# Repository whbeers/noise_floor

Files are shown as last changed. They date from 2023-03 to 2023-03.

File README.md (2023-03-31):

# Noise Floor interface board collection

This is set of interface boards to speed effect pedal development, continuing my efforts to learn PCB design with [KiCAD](https://www.kicad.org/).

### IO and Switch boards
The first board is an audio input and power board, featuring:
  - Switched DC barrel jack supporting either a 9VDC center negative supply or 9V battery
  - Mono audio jacks w/ switched input circuit (ring/ground shorted to sleeve on insertion)
  - Basic power input protection

The IO PCB is designed to fit in a standard 125B enclosure.

The second board simplifies effect bypass via a 3PDT switch adapter with an LED indicator.

#### Connectivity (cabled)
IO, Effect, and Switch boards are connected using four-circuit [Molex PicoBlade](https://www.molex.com/molex/products/family/picoblade?parentKey=wire_to_board_connectors) connectors.

Headers are labelled symmetrically from the perspective of the IO board:
 - **S**1 on IO Board <-> **S**1 on **S**witch Board
 - **S**2 on IO Board <-> **S**2 on **S**witch Board
 - **E**1 on IO Board <-> **E**1 on **E**ffect Board

### UX PCB (experimental)
The third and newest (experimental) board is a UX board providing a standard superset of potentiometers and switches. It is intended to connect to an effects board using two 25-position [Amphenol "Conan Lite"](https://www.amphenol-cs.com/product-series/conan-lite-1-00mm.html) board-to-board connectors.

The current iteration of the UX board supports six potentiometers and three SPDT switches, but alternative control layouts are an obvious extension. Each potentiometer on the current prototype can be adjusted using optional parallel resistors (SMD 1206) to tweak the taper and total resistance.

#### Connectivity (board-to-board)
The effect and UX boards are connected using [Amphenol "Conan Lite"](https://www.amphenol-cs.com/product-series/conan-lite-1-00mm.html) board-to-board connectors. Only a single UX board variety currently exists, supporting a superset of six potentiometers and three SPDT switches. As the UX board is in the experimental/proof-of-concept phase, the pin assignment should be considered preliminary and subject to change.

Current connector allocation:
 - 6x Potentiometers x 3 (CCW, Wiper, CW) = 18
 - 3x SPDT switches x 3 (NO, COM, NC) = 9
 - 4x Reserved for ground
 - Total used: 31
 - Remaining for expansion: 19
 
Ideas for future boards / changes:
 - Allocate connector positions for a single DPDT switch (+3, reusing 3 from an existing SPDT)
 - Incorporate linear potentiometers into an alternate IO board
 - Allocate at least 12 positions for "flexible use" (enough to support a 4PDT switch)
 - Allocate positions to drive (RGB?) LEDs with standardized current-limiting resistors

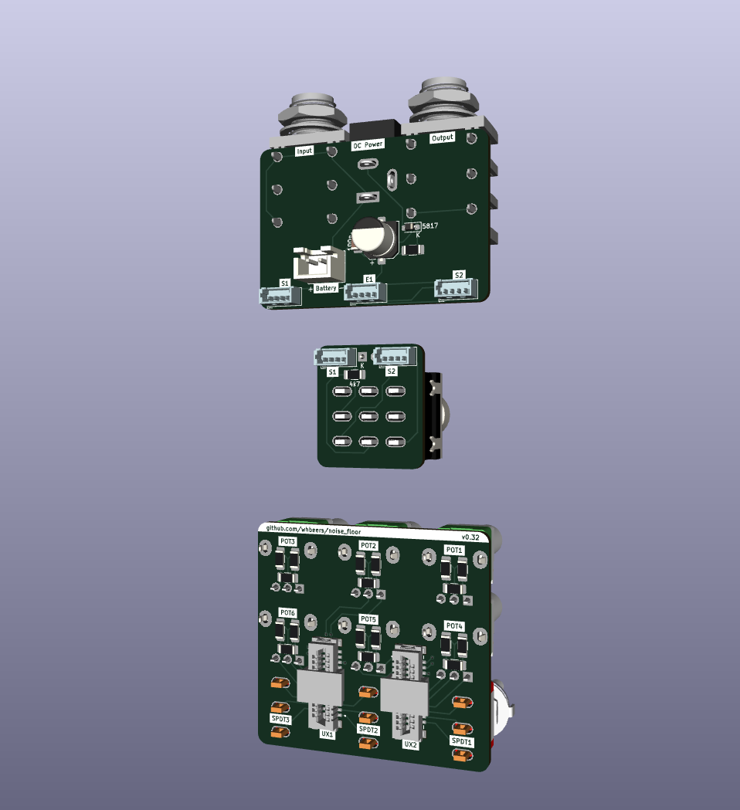
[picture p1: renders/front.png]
Front render

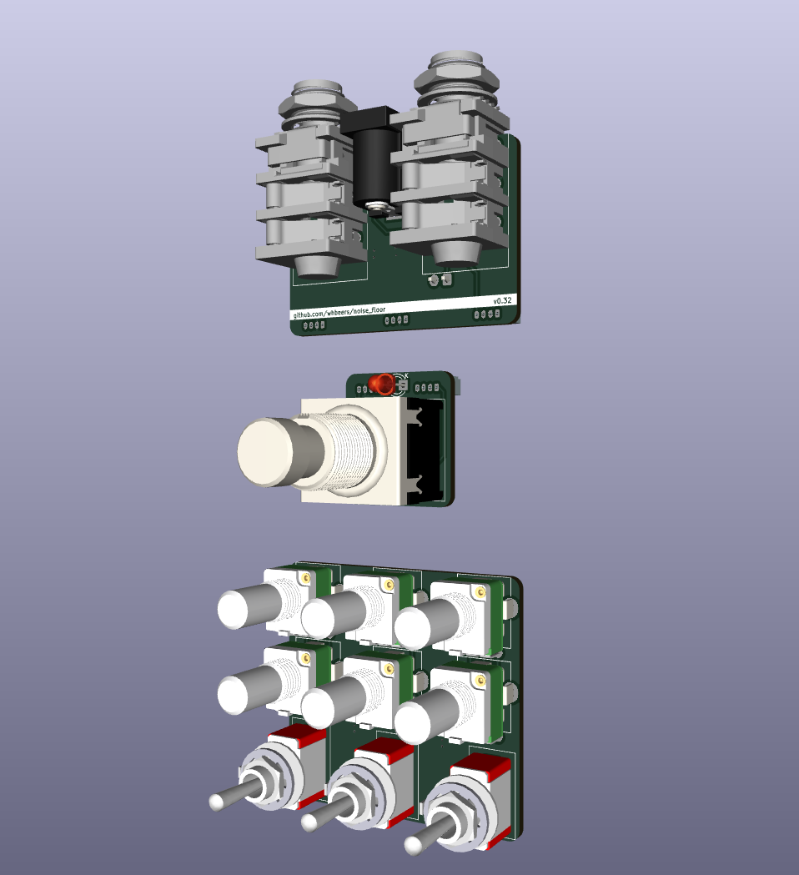
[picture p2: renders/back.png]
Back render

Schematic SVG
[Schematic PDF](schematics/noise_floor-latest.pdf)

## Credit

The original idea and specific bypass circuit is inspired by many manufacturers of utility PCBs and well-known circuits for 3PDT-based effect bypass, notably [PedalPCB's 3PDT breakout](https://www.pedalpcb.com/product/3pdt/), augmented to suit my needs.

Thanks as always to the folks on the [freestompboxes.org](https://www.freestompboxes.org/) forum for feedback and suggestions.

Potentiometer, 3PDT footswitch, and DC barrel jack 3D models courtesy [Vasily Kashirin](https://grabcad.com/vasily.kashirin-1).

SPDT toggle switch 3D model courtesy [Stephanie Schwecke](https://grabcad.com/stephanie.schwecke-1).

Conan Lite footprints adapted from the 51-position footprints available from SnapEDA: [Header](https://www.snapeda.com/parts/10162582-1134151LF/Amphenol%20ICC%20(FCI)/view-part/), [Receptacle](https://www.snapeda.com/parts/10162581-3134151LF/Amphenol%20ICC%20(FCI)/view-part/).([Additional license details](hardware/SnapEDA_Licensing.txt)). 3D models courtesy Amphenol.

*I am not affiliated with any of the brands, sites, or products named in this overview.*

## Future plans

 - Build an IO board that includes a TRS expression pedal input (started this way, but found it hard to fit in a 125B enclosure)
 - Support stereo operation via relays, optoisolators, or a "millenium" switch

## Versioning

My pcb designs utilize the following versioning scheme (I'll add to this as I produce more revisions):
 - v0.0XX: A candidate design that has not yet been produced and tested.
 - v0.XX: A design that has been produced, tested, and any initial errors addressed.

## Name
*The name Noise Floor is a reflection of the function of the board (a substrate for pedals and bypass circuit) and security nerdery.*

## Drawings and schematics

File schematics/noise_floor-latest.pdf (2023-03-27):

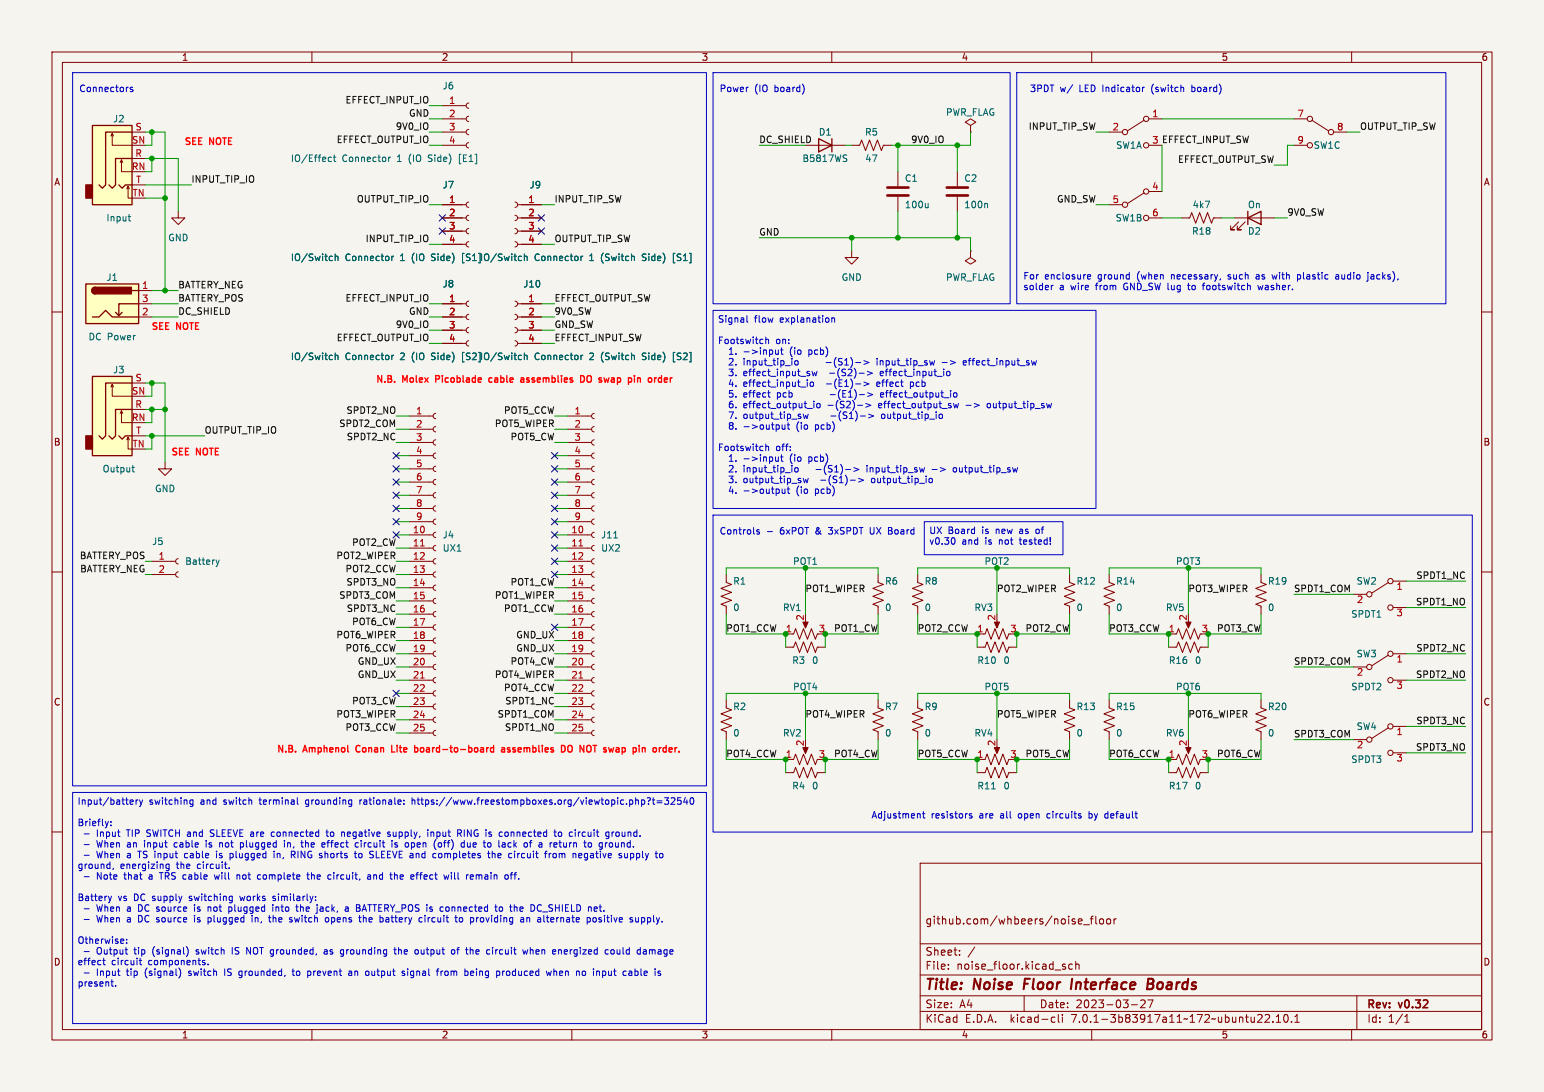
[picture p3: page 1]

Id: 1/1 Title: Noise Floor Interface Boards

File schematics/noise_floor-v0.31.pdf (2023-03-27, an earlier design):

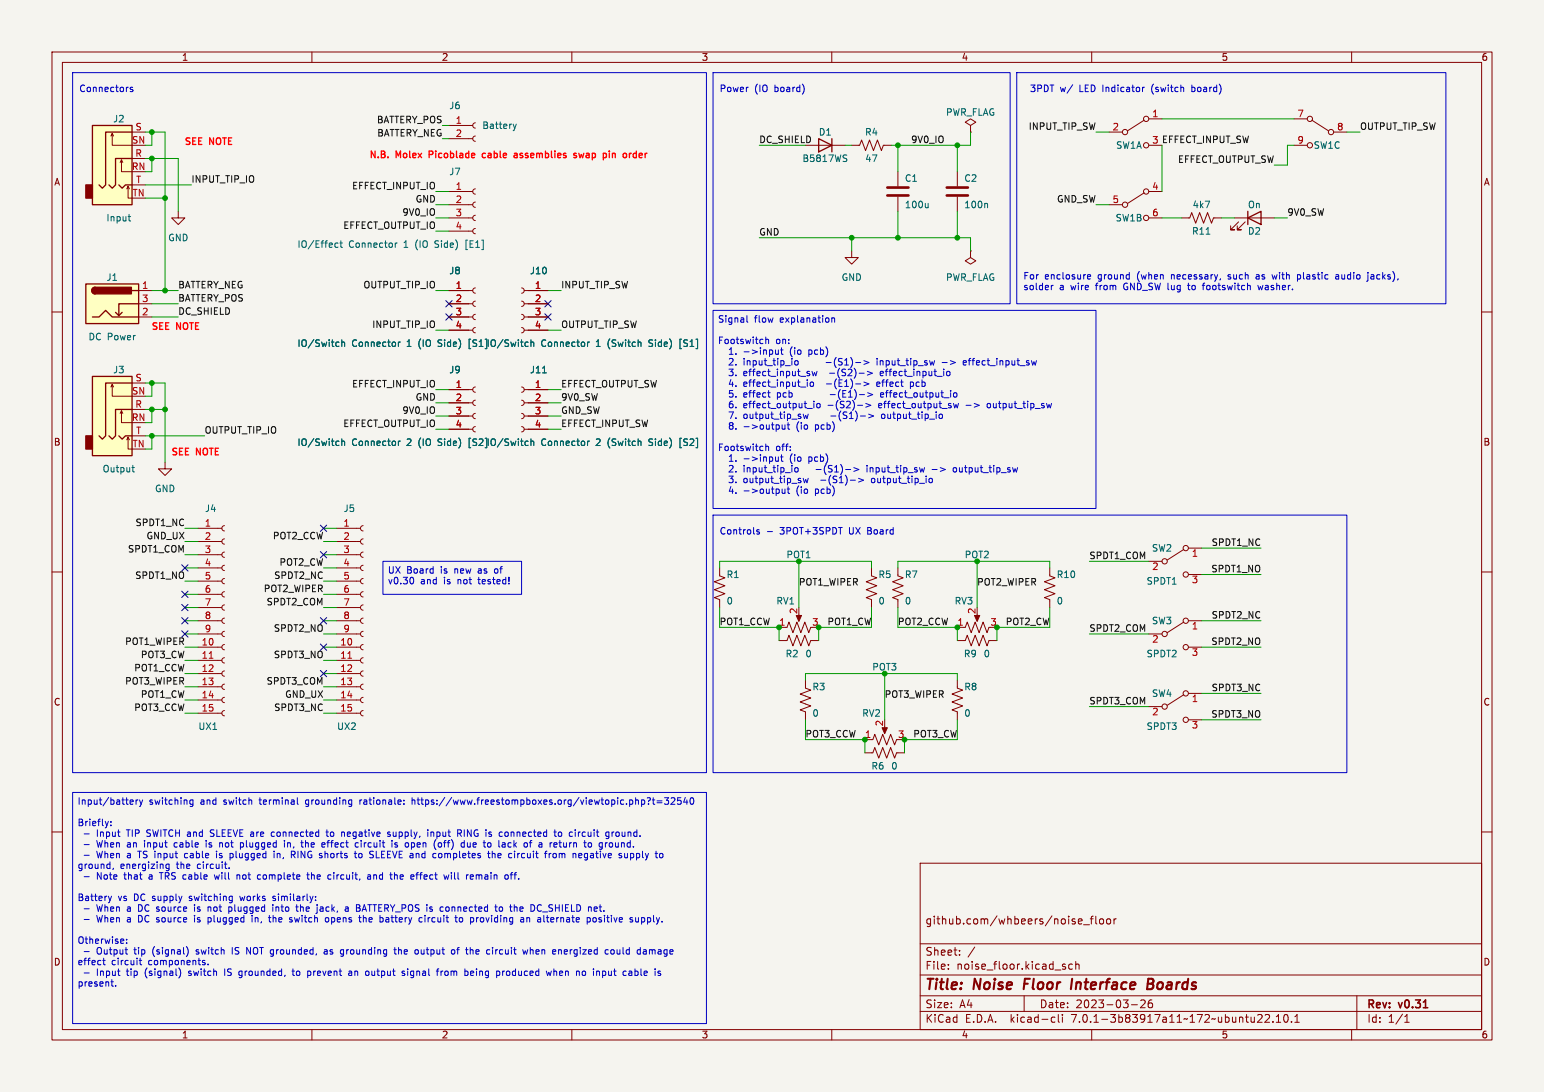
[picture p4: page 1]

File: noise_floor.kicad_sch Sheet: / github.com/whbeers/noise_floor

Id: 1/1 Title: Noise Floor Interface Boards

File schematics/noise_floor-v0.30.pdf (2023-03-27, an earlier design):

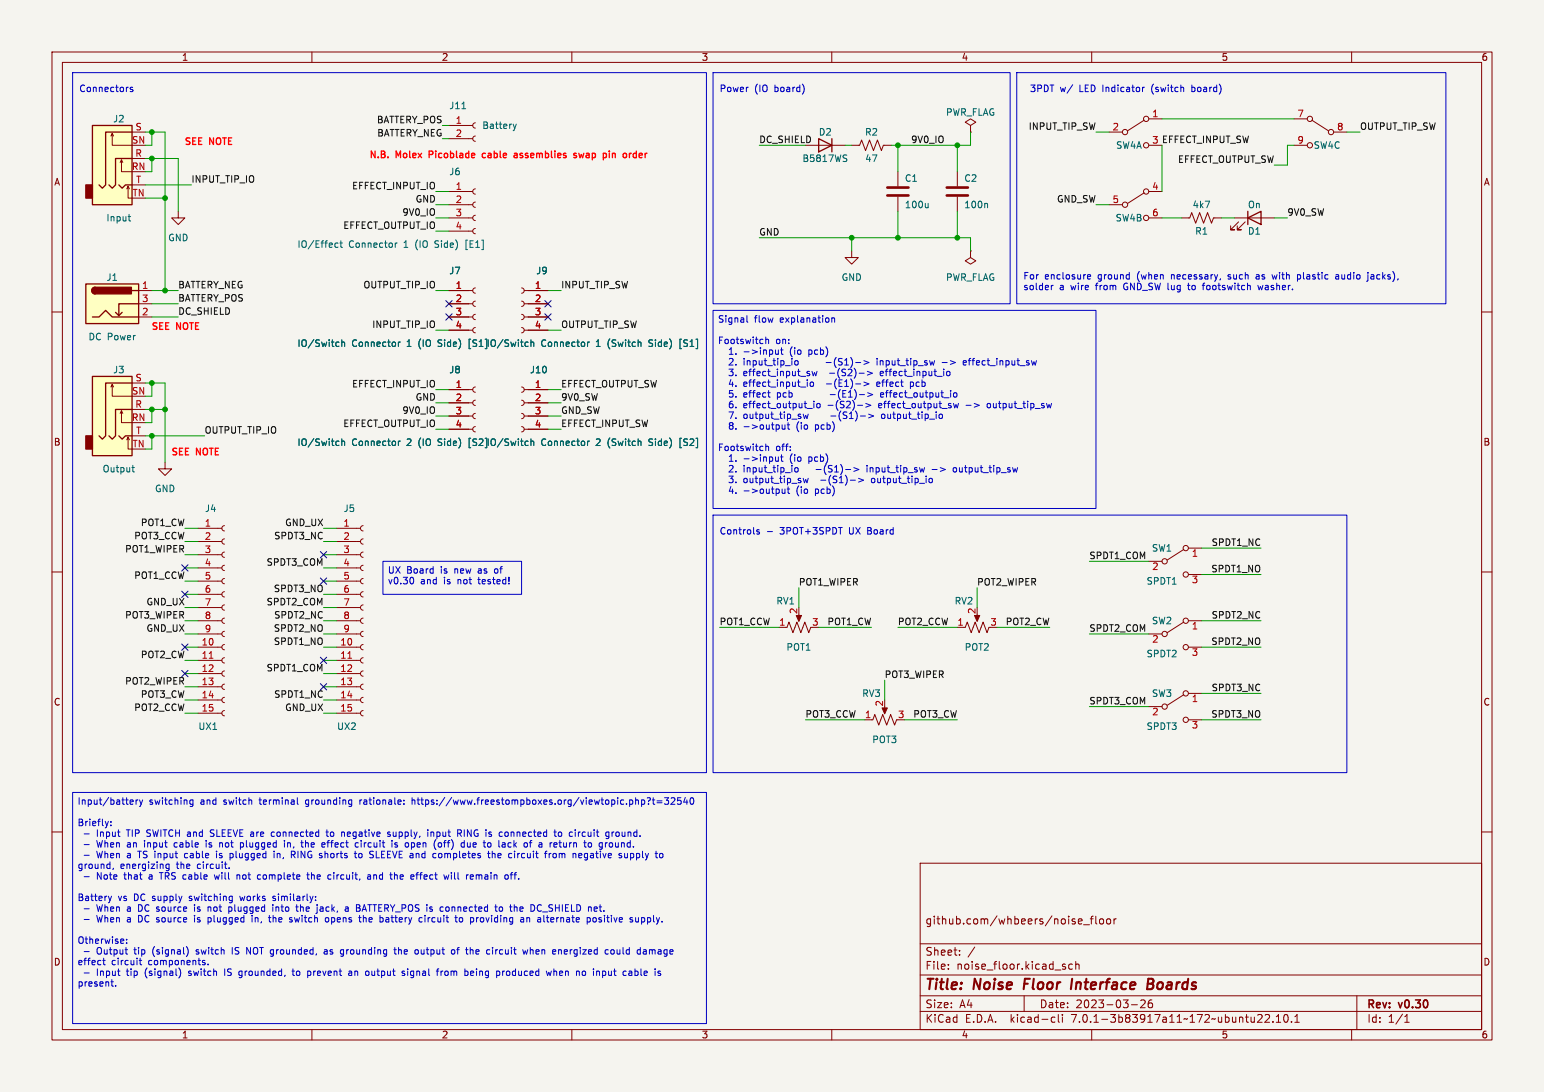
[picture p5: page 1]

File: noise_floor.kicad_sch Sheet: / github.com/whbeers/noise_floor

Id: 1/1 Title: Noise Floor Interface Boards

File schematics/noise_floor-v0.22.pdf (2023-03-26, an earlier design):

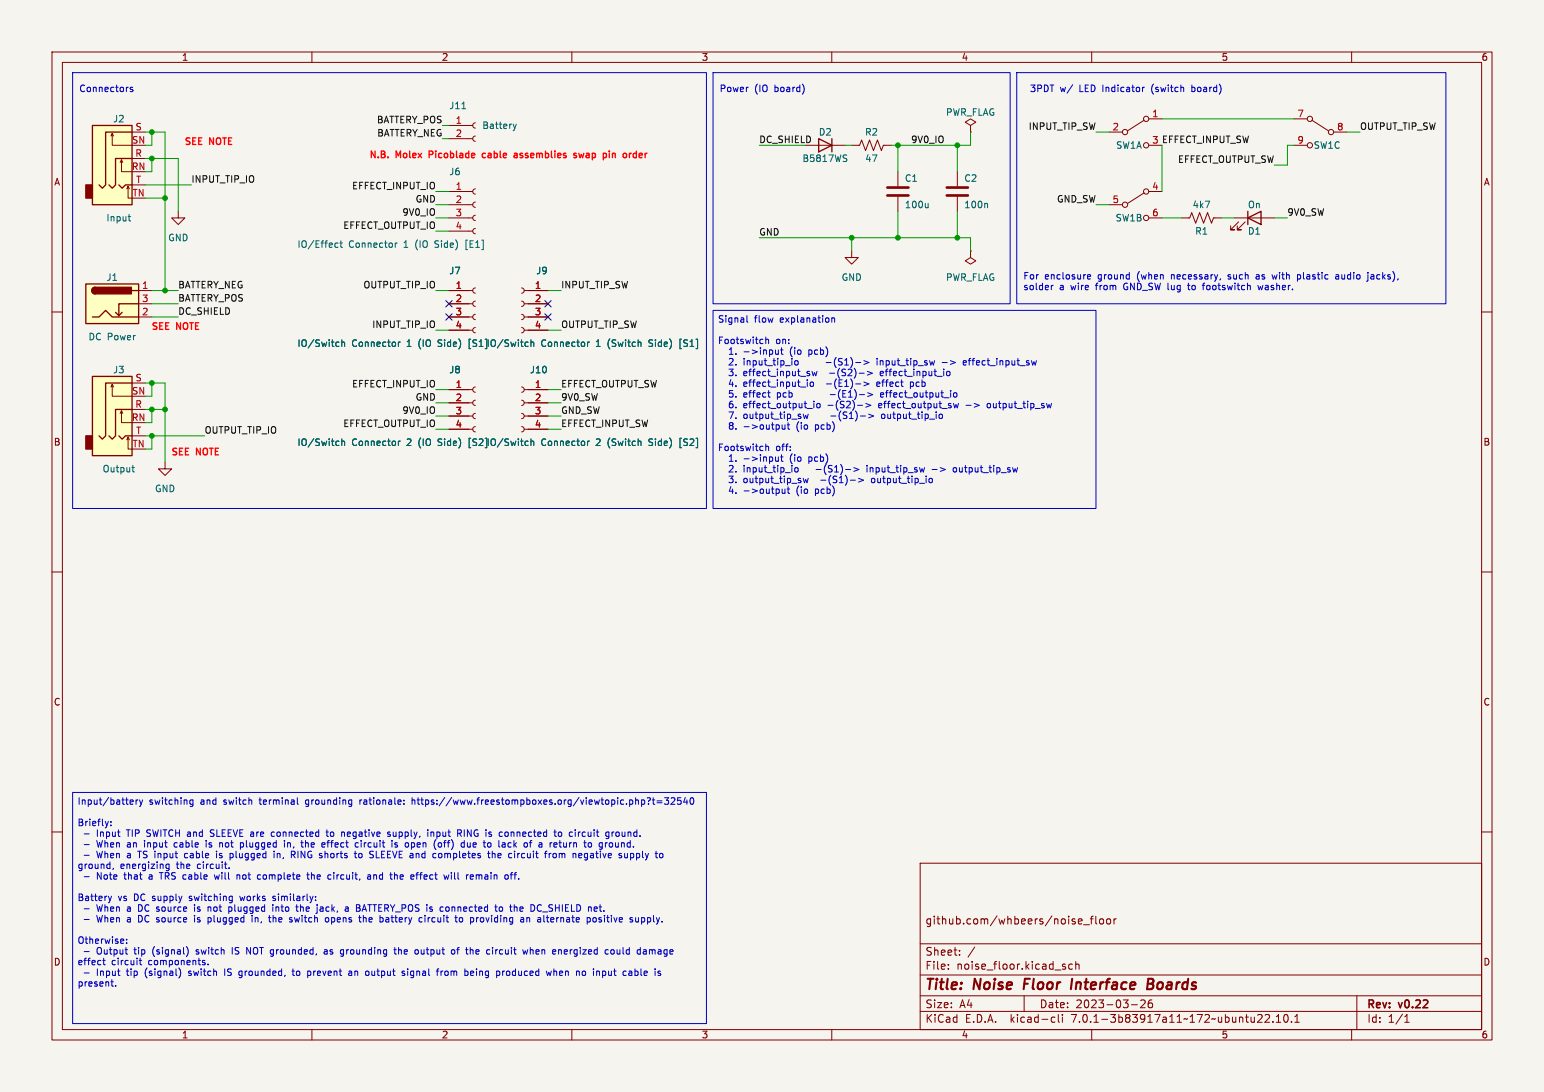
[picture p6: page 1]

File: noise_floor.kicad_sch Sheet: / github.com/whbeers/noise_floor

Id: 1/1 Title: Noise Floor Interface Boards

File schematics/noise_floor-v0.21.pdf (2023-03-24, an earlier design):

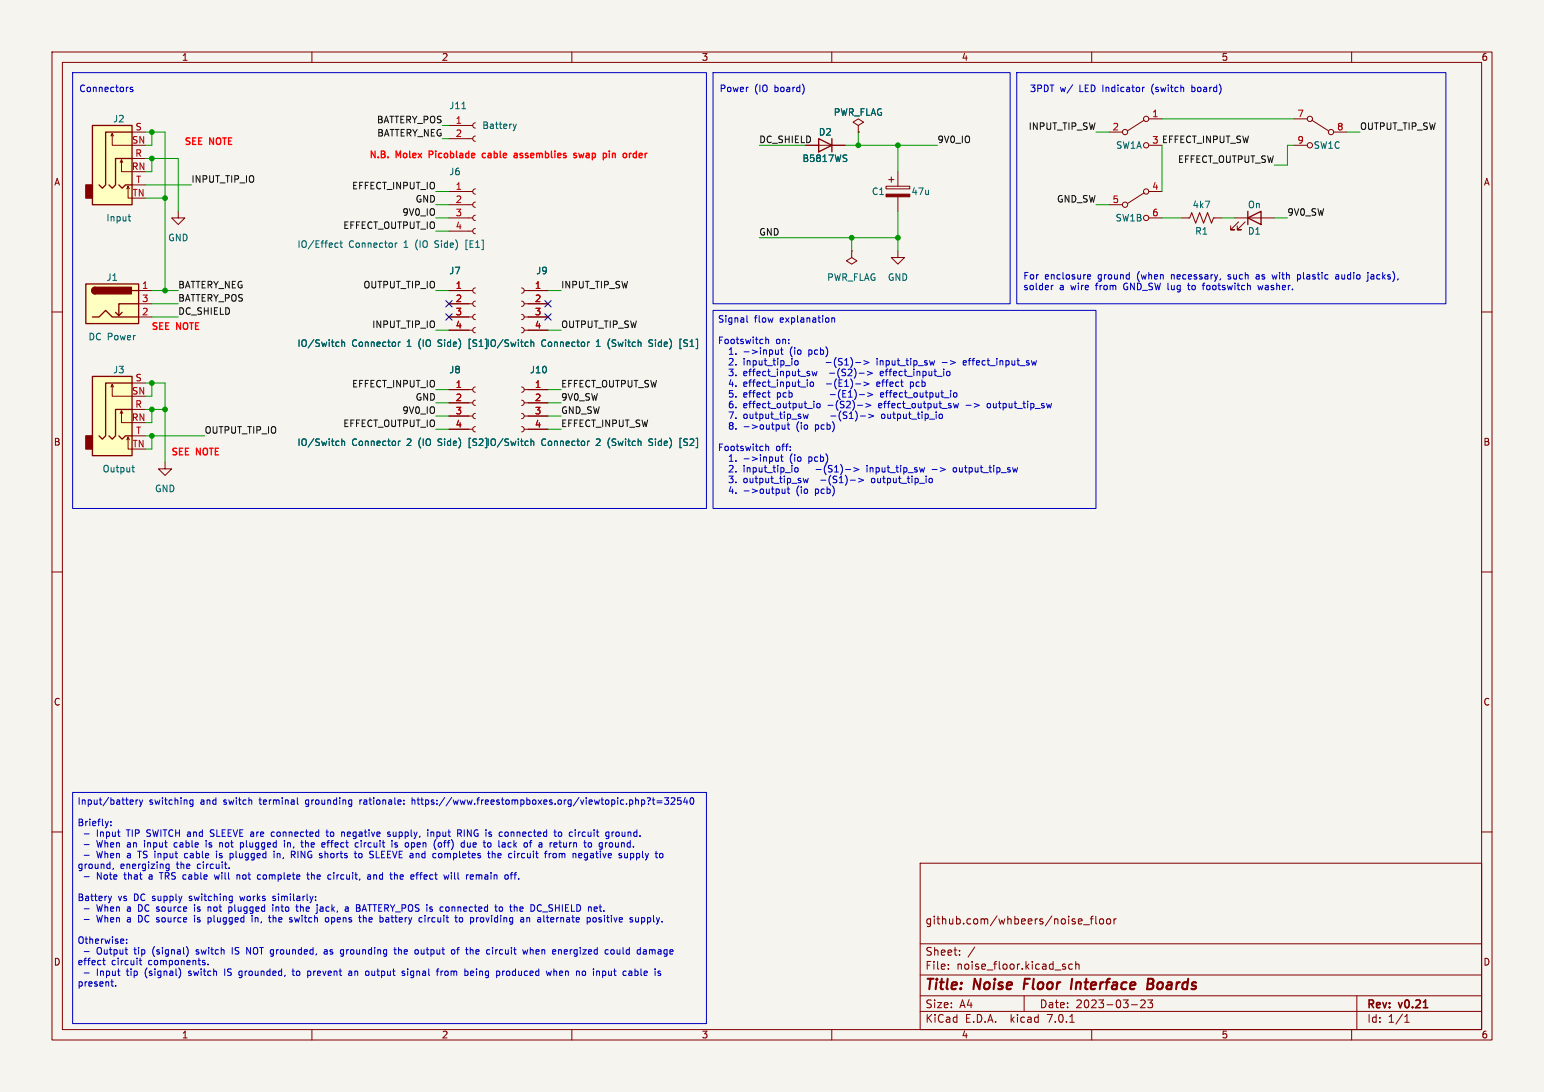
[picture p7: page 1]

File: noise_floor.kicad_sch Sheet: / github.com/whbeers/noise_floor

Id: 1/1 Title: Noise Floor Interface Boards

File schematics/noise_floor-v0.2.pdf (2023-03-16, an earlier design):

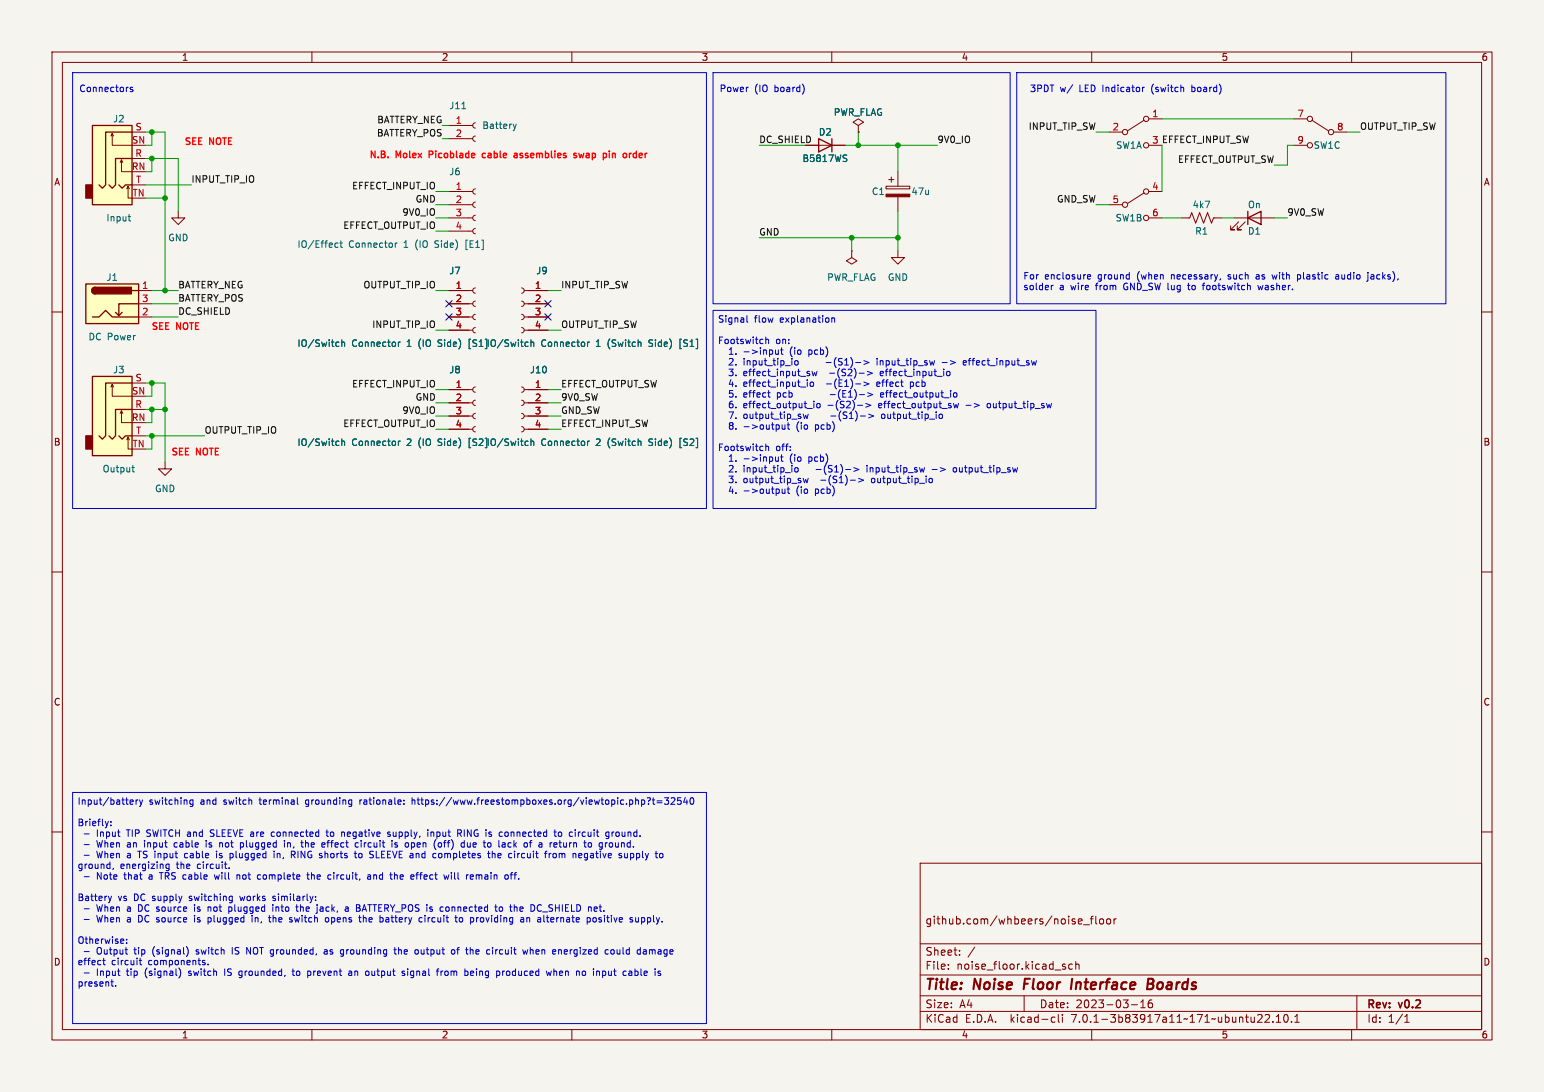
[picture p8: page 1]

Power (IO board) N.B. Molex Picoblade cable assemblies swap pin order SEE NOTE

File: noise_floor.kicad_sch Sheet: / github.com/whbeers/noise_floor

Id: 1/1 Title: Noise Floor Interface Boards

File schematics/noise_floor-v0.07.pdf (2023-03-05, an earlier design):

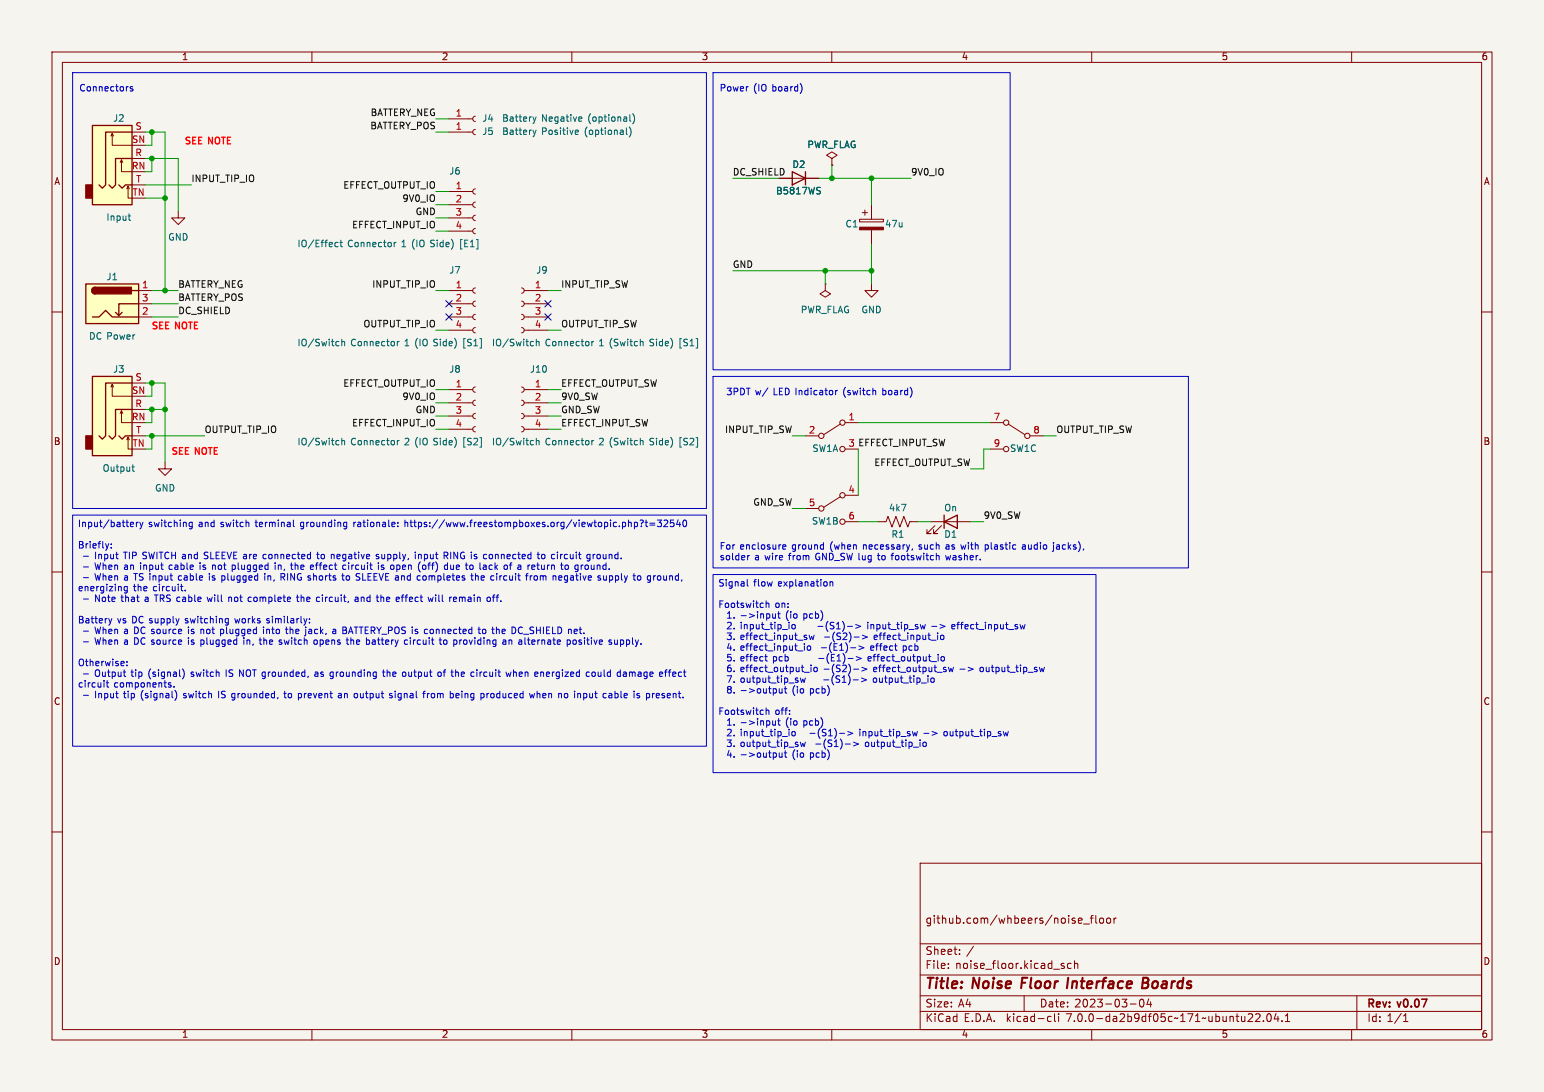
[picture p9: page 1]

File: noise_floor.kicad_sch Sheet: / github.com/whbeers/noise_floor

Id: 1/1 Title: Noise Floor Interface Boards

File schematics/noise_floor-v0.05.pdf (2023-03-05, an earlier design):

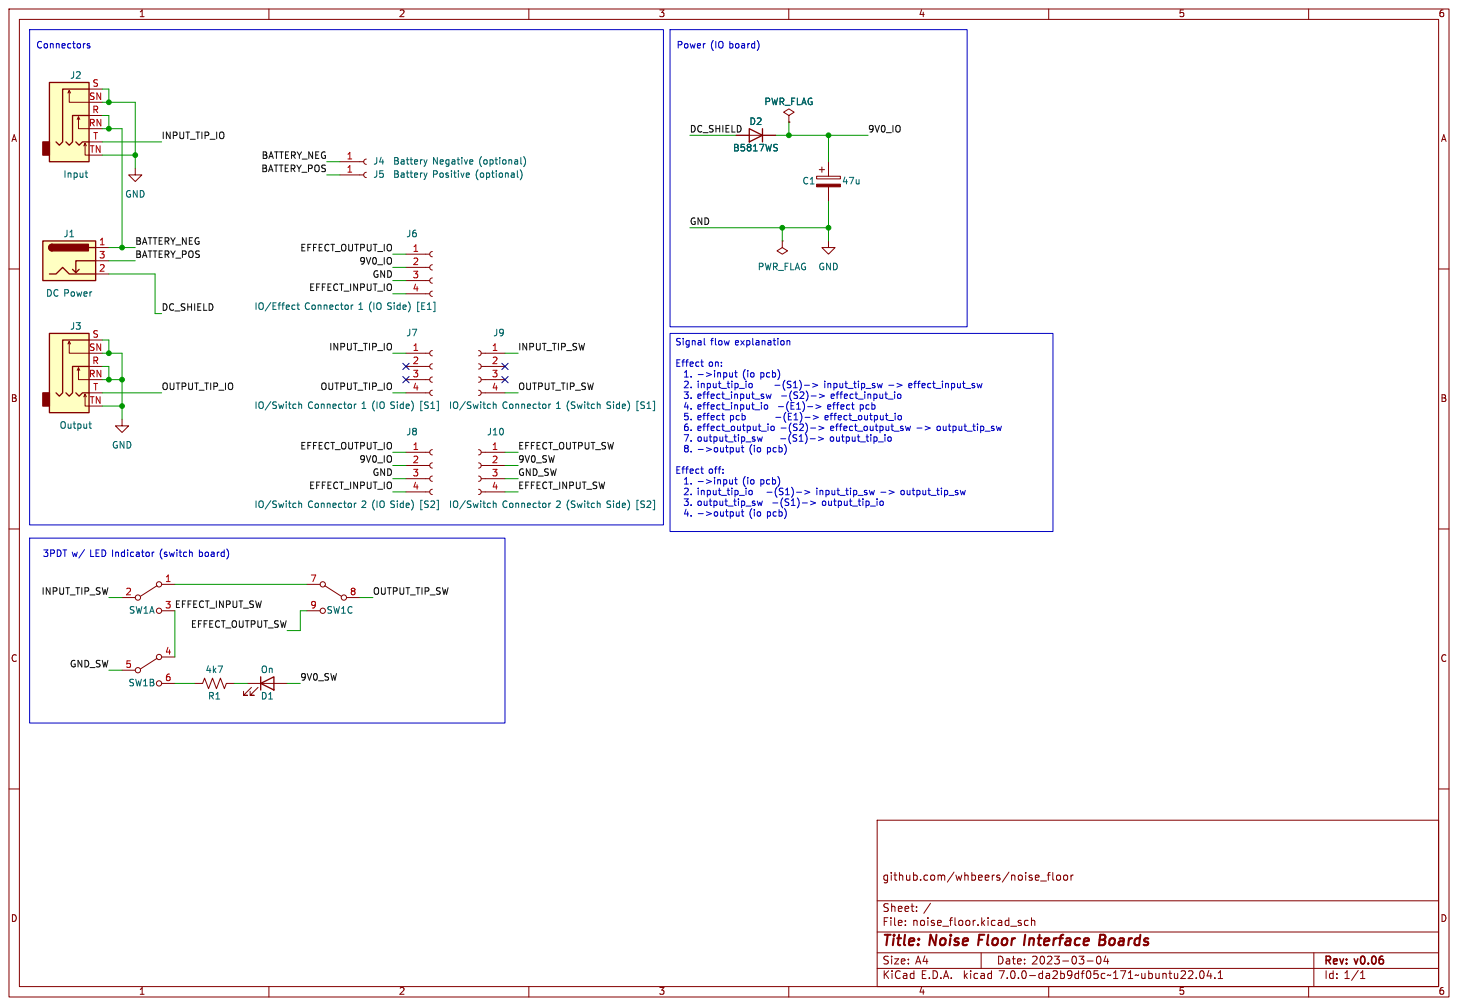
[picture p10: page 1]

File: noise_floor.kicad_sch Sheet: / github.com/whbeers/noise_floor D1 On

Id: 1/1 Title: Noise Floor Interface Boards

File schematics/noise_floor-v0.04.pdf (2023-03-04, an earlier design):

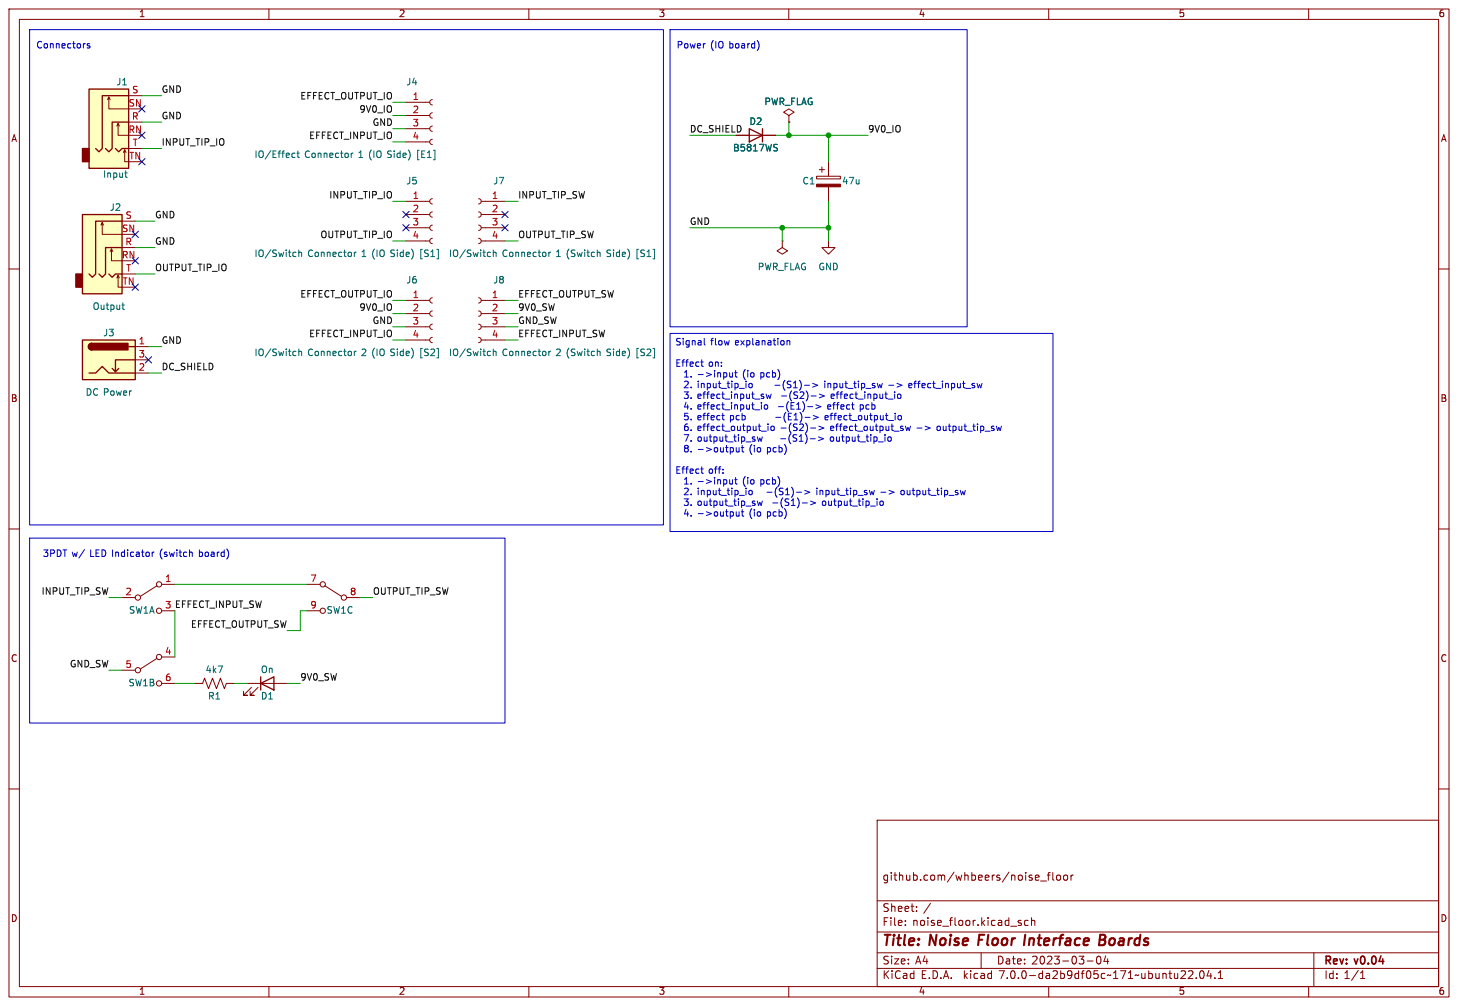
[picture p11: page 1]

File: noise_floor.kicad_sch Sheet: / github.com/whbeers/noise_floor

Id: 1/1 Title: Noise Floor Interface Boards

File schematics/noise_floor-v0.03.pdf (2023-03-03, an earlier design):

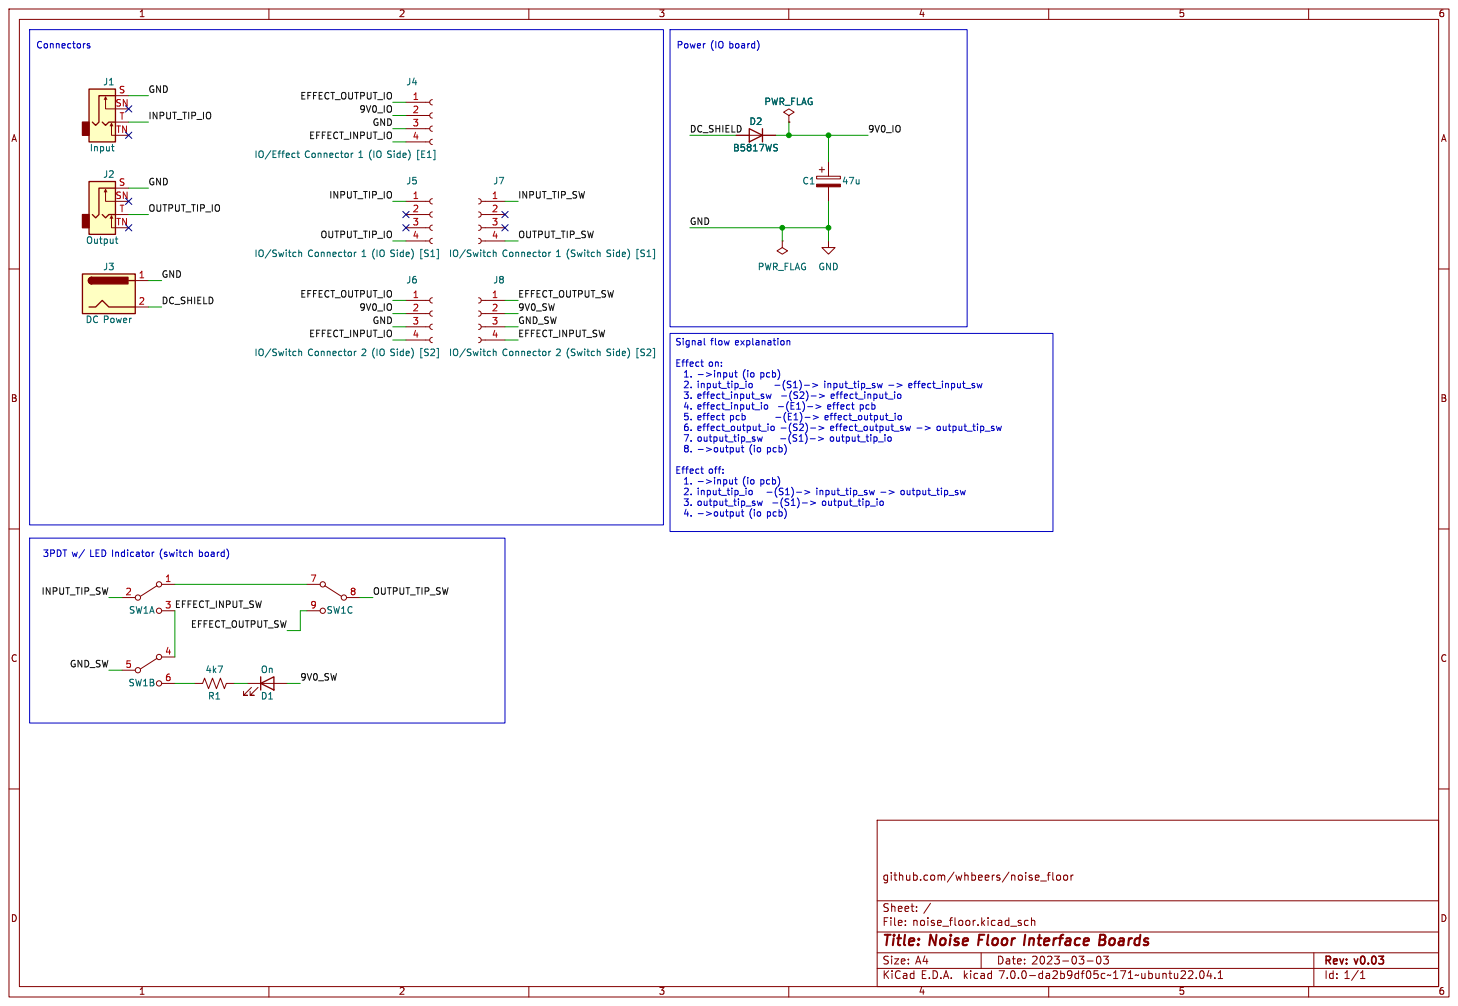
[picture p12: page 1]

File: noise_floor.kicad_sch Sheet: / github.com/whbeers/noise_floor

Id: 1/1 Title: Noise Floor Interface Boards

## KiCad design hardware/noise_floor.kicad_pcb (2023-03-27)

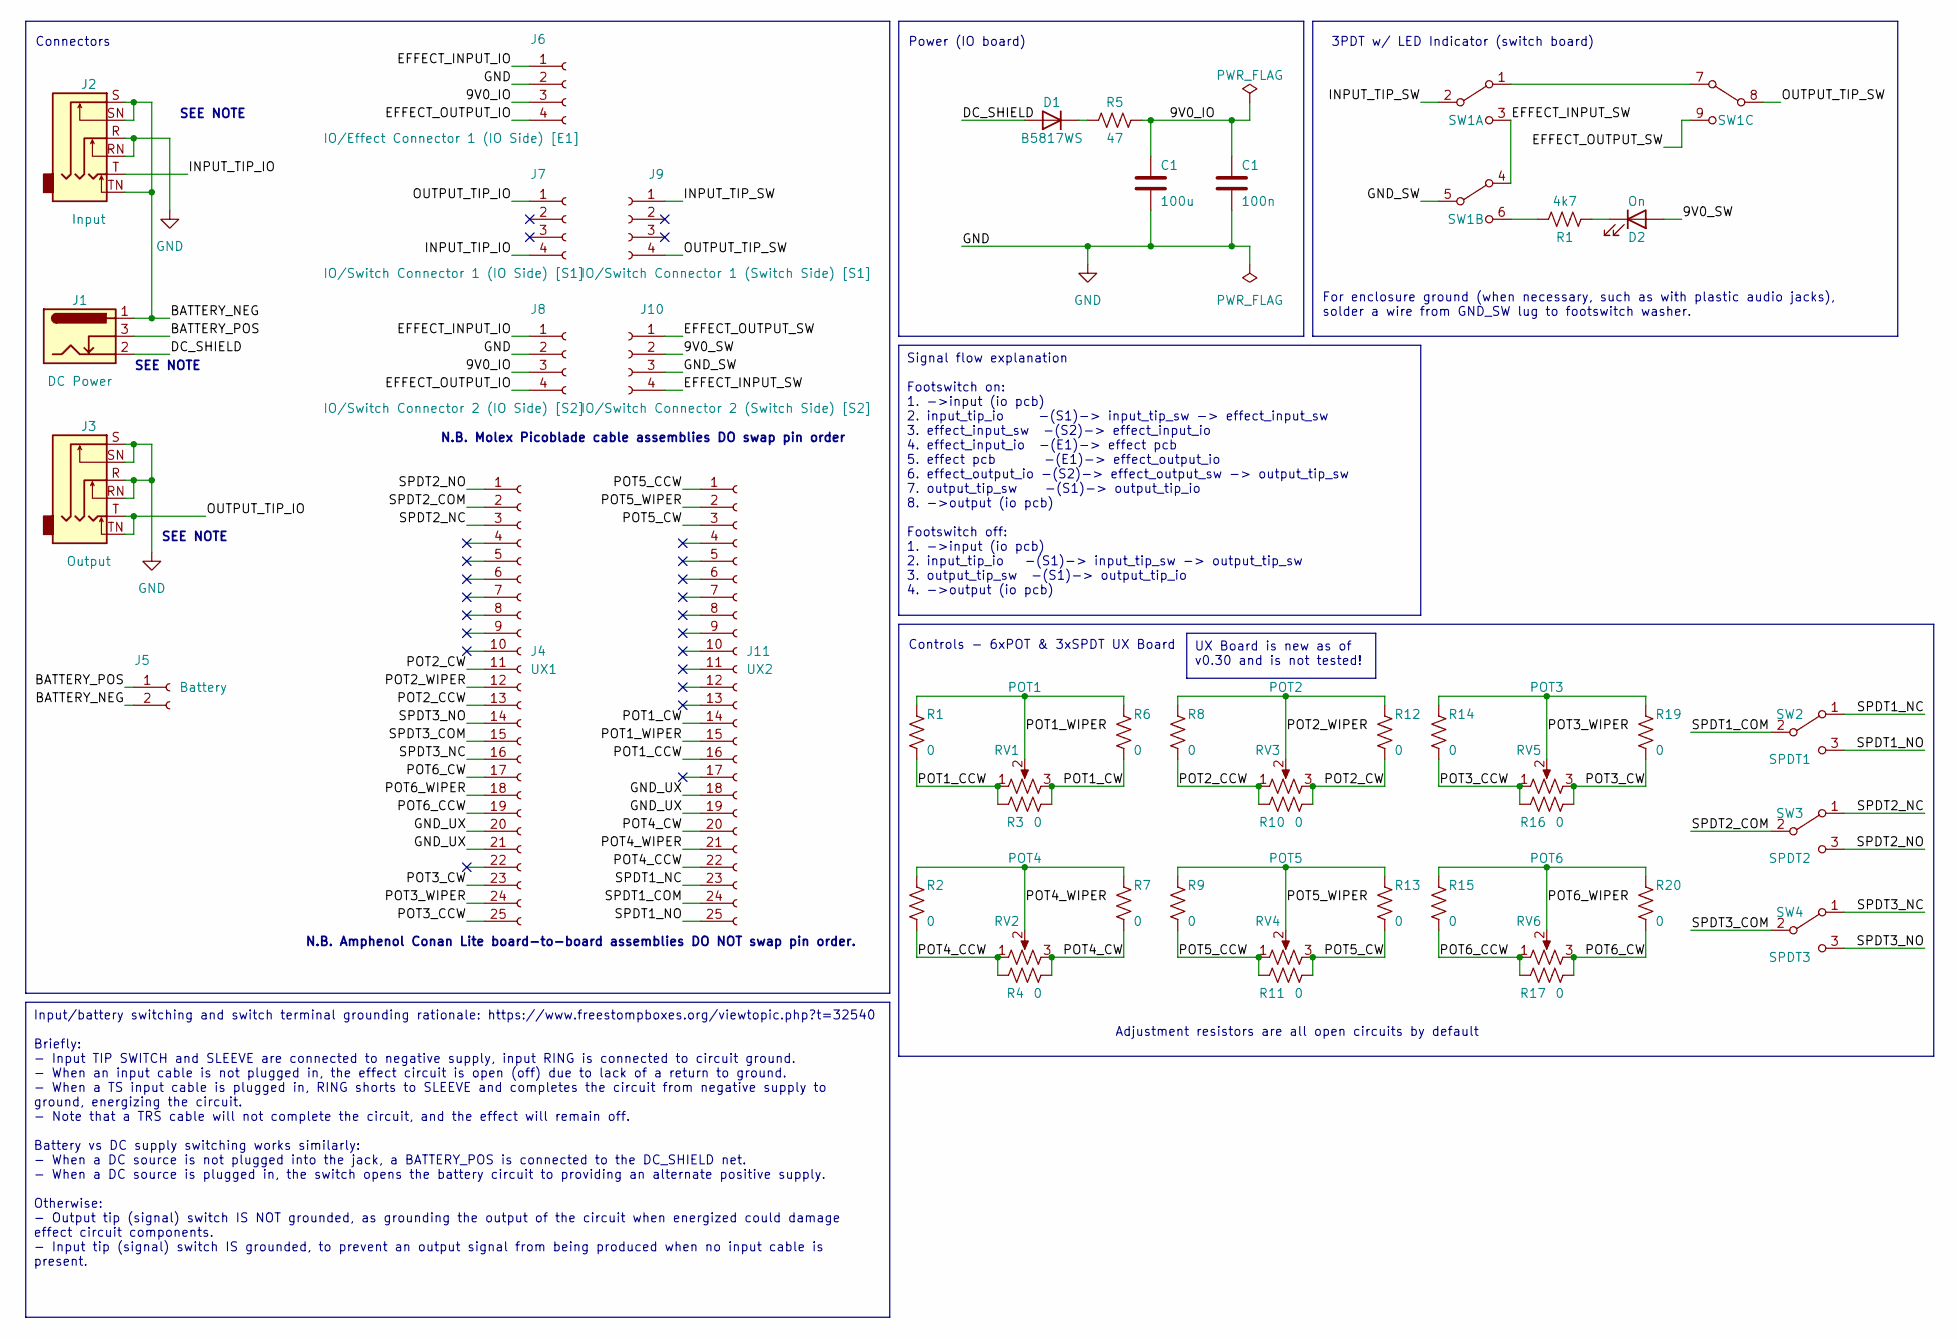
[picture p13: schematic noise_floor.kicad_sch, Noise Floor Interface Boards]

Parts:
C1: 100n; C_1206_3216Metric
D1: B5817WS; D_SOD-323_HandSoldering
D2: On; LED_D3.0mm
J1: DC Power; BarrelJack_GCT_DCJ200-10-A_Horizontal_with_3DModel_from_Vas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
J2: Input; ACJS-MHOM
J3: Output; ACJS-MHOM
J4: UX1; Amphenol_Receptacle_25pin_10162581-3134125LF
J5: Battery; JST_XH_B2B-XH-A_1x02_P2.50mm_Vertical
J6: IO/Effect Connector 1 (IO Side) [E1]; Molex_PicoBlade_53047-0410_1x04_P1.25mm_Vertical_with_3D_Mo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
J7: IO/Switch Connector 1 (IO Side) [S1]; Molex_PicoBlade_53047-0410_1x04_P1.25mm_Vertical_with_3D_Mo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
J8: IO/Switch Connector 2 (IO Side) [S2]; Molex_PicoBlade_53047-0410_1x04_P1.25mm_Vertical_with_3D_Mo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
J9: IO/Switch Connector 1 (Switch Side) [S1]; Molex_PicoBlade_53047-0410_1x04_P1.25mm_Vertical_with_3D_Mo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
J10: IO/Switch Connector 2 (Switch Side) [S2]; Molex_PicoBlade_53047-0410_1x04_P1.25mm_Vertical_with_3D_Mo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
J11: UX2; Amphenol_Receptacle_25pin_10162581-3134125LF
R1: 4k7; R_1206_3216Metric_Pad1.30x1.75mm_HandSolder
R2, R3, R4, R6, R7, R8, R9, R10, R11, R12, R13, R14, R15, R16, R17, R19, R20: 0; R_1206_3216Metric_Pad1.30x1.75mm_HandSolder
R5: 47; R_1206_3216Metric_Pad1.30x1.75mm_HandSolder
RV1: POT1; Potentiometer_Alpha_RD901F-40-00D_Single_Vertical_with_3DMo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
RV2: POT4; Potentiometer_Alpha_RD901F-40-00D_Single_Vertical_with_3DMo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
RV3: POT2; Potentiometer_Alpha_RD901F-40-00D_Single_Vertical_with_3DMo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
RV4: POT5; Potentiometer_Alpha_RD901F-40-00D_Single_Vertical_with_3DMo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
RV5: POT3; Potentiometer_Alpha_RD901F-40-00D_Single_Vertical_with_3DMo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
RV6: POT6; Potentiometer_Alpha_RD901F-40-00D_Single_Vertical_with_3DMo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
SW1: Footswitch; SW_3PDT_SOLDER_LUGS
SW2: SPDT1; SW_SPDT_SOLDER_LUGS
SW3: SPDT2; SW_SPDT_SOLDER_LUGS
SW4: SPDT3; SW_SPDT_SOLDER_LUGS

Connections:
/9V0_IO: C1.1, J6.3, J8.3, R5.1; also elsewhere on the board
/9V0_SW: D2.2 (A), J10.2
/BATTERY_NEG: J1.1, J2.S, J2.SN, J2.TN, J5.2
/BATTERY_POS: J1.3, J5.1
/DC_SHIELD: D1.2 (A), J1.2
/EFFECT_INPUT_IO: J6.1, J8.1
/EFFECT_INPUT_SW: J10.4, SW1.3 (A3), SW1.4 (B1)
/EFFECT_OUTPUT_IO: J6.4, J8.4
/EFFECT_OUTPUT_SW: J10.1, SW1.9 (C3)
/GND_SW: J10.3, SW1.5 (B2)
/GND_UX: J4.20, J4.21, J11.18, J11.19
/INPUT_TIP_IO: J2.T, J7.4
/INPUT_TIP_SW: J9.1, SW1.2 (A2)
/OUTPUT_TIP_IO: J3.T, J3.TN, J7.1
/OUTPUT_TIP_SW: J9.4, SW1.8 (C2)
/POT1_CW: J11.14, R3.1, R6.1, RV1.3
/POT2_CCW: J4.13, R8.1, R10.2, RV3.1
/POT2_CW: J4.11, R10.1, R12.1, RV3.3
/POT2_WIPER: J4.12, R8.2, R12.2, RV3.2
/POT3_CCW: J4.25, R14.1, R16.2, RV5.1
/POT3_CW: J4.23, R16.1, R19.1, RV5.3
/POT3_WIPER: J4.24, R14.2, R19.2, RV5.2
/POT4_CCW: J11.22, R2.1, R4.2, RV2.1
/POT4_CW: J11.20, R4.1, R7.1, RV2.3
/POT4_WIPER: J11.21, R2.2, R7.2, RV2.2
/POT5_CCW: J11.1, R9.1, R11.2, RV4.1
/POT5_CW: J11.3, R11.1, R13.1, RV4.3
/POT5_WIPER: J11.2, R9.2, R13.2, RV4.2
/POT6_CCW: J4.19, R15.1, R17.2, RV6.1
/POT6_CW: J4.17, R17.1, R20.1, RV6.3
/POT6_WIPER: J4.18, R15.2, R20.2, RV6.2
/SPDT1_COM: J11.24, SW2.2 (B)
/SPDT1_NC: J11.23, SW2.1 (A)
/SPDT1_NO: J11.25, SW2.3 (C)
/SPDT2_COM: J4.2, SW3.2 (B)
/SPDT2_NC: J4.3, SW3.1 (A)
/SPDT2_NO: J4.1, SW3.3 (C)
/SPDT3_COM: J4.15, SW4.2 (B)
/SPDT3_NC: J4.16, SW4.1 (A)
/SPDT3_NO: J4.14, SW4.3 (C)
GND: C1.2, J2.R, J2.RN, J3.R, J3.RN, J3.S, J3.SN, J6.2, J8.2; also elsewhere on the board
unnamed: D1.1 (K), R5.2
unnamed: SW1.1 (A1), SW1.7 (C1)

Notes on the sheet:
Input/battery switching and switch terminal grounding rationale: https://www.freestompboxes.org/viewtopic.php?t=32540 Briefly: - Input TIP SWITCH and SLEEVE are connected to negative supply, input RING is connected to circuit ground. - When an input cable is not plugged in, the effect circuit is op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
Signal flow explanation Footswitch on: 1. ->input (io pcb) 2. input_tip_io -(S1)-> input_tip_sw -> effect_input_sw 3. effect_input_sw -(S2)-> effect_input_io 4. effect_input_io -(E1)-> effect pcb 5. effect pcb -(E1)-> effect_output_io 6. effect_output_io -(S2)-> effect_output_sw -> output_tip_sw 7.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
UX Board is new as of v0.30 and is not tested!
Connectors
For enclosure ground (when necessary, such as with plastic audio jacks), solder a wire from GND_SW lug to footswitch washer.
3PDT w/ LED Indicator (switch board)
SEE NOTE
Power (IO board)
Controls - 6xPOT & 3xSPDT UX Board
N.B. Amphenol Conan Lite board-to-board assemblies DO NOT swap pin order.
Adjustment resistors are all open circuits by default
N.B. Molex Picoblade cable assemblies DO swap pin order

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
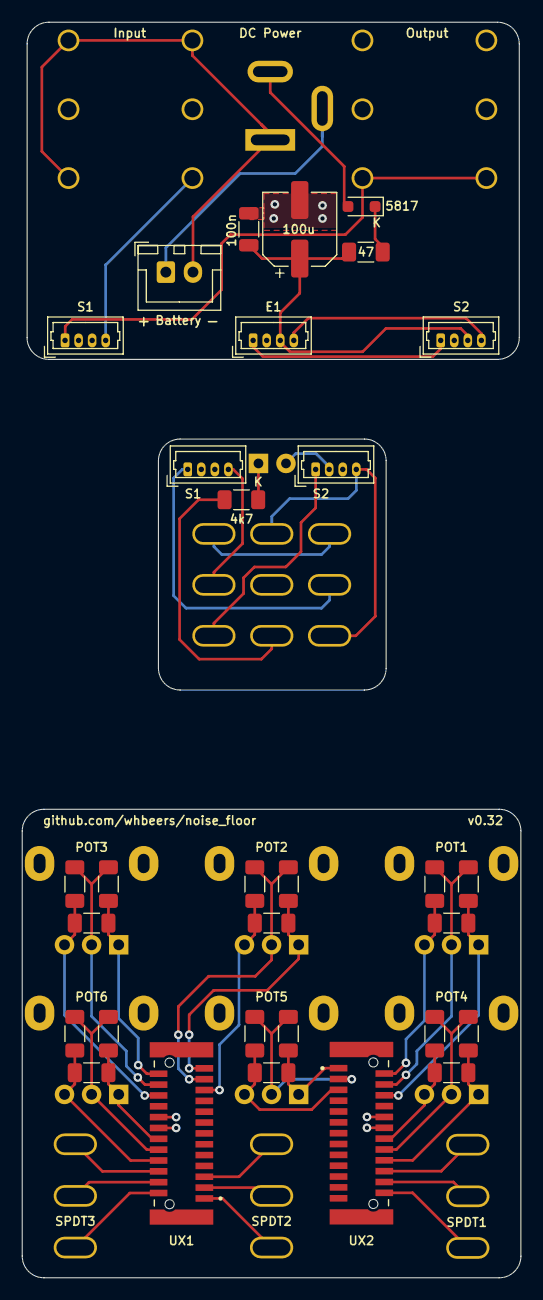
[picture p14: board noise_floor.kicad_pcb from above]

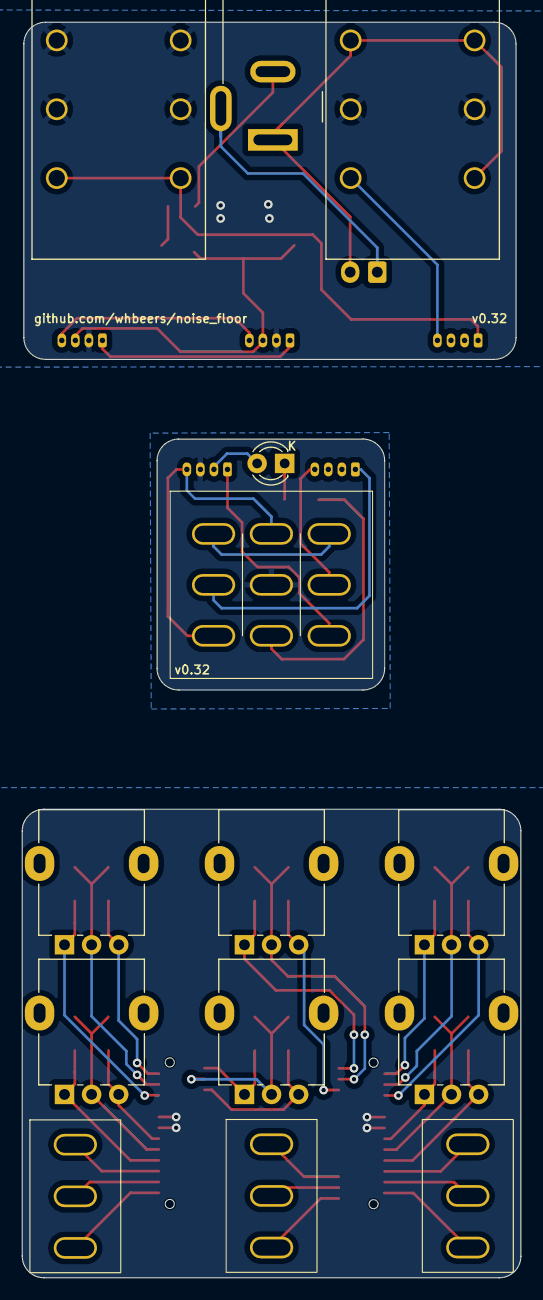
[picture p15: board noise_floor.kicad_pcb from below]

Board: 2 copper layers, 46.0 x 115.8 mm, 45 parts (14 on the bottom side), 47 nets.

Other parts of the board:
C2: 100n; C_1206_3216Metric
R18: 4k7; R_1206_3216Metric_Pad1.30x1.75mm_HandSolder

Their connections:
/9V0_IO: C2.1; also elsewhere on the board
GND: C2.2; also elsewhere on the board

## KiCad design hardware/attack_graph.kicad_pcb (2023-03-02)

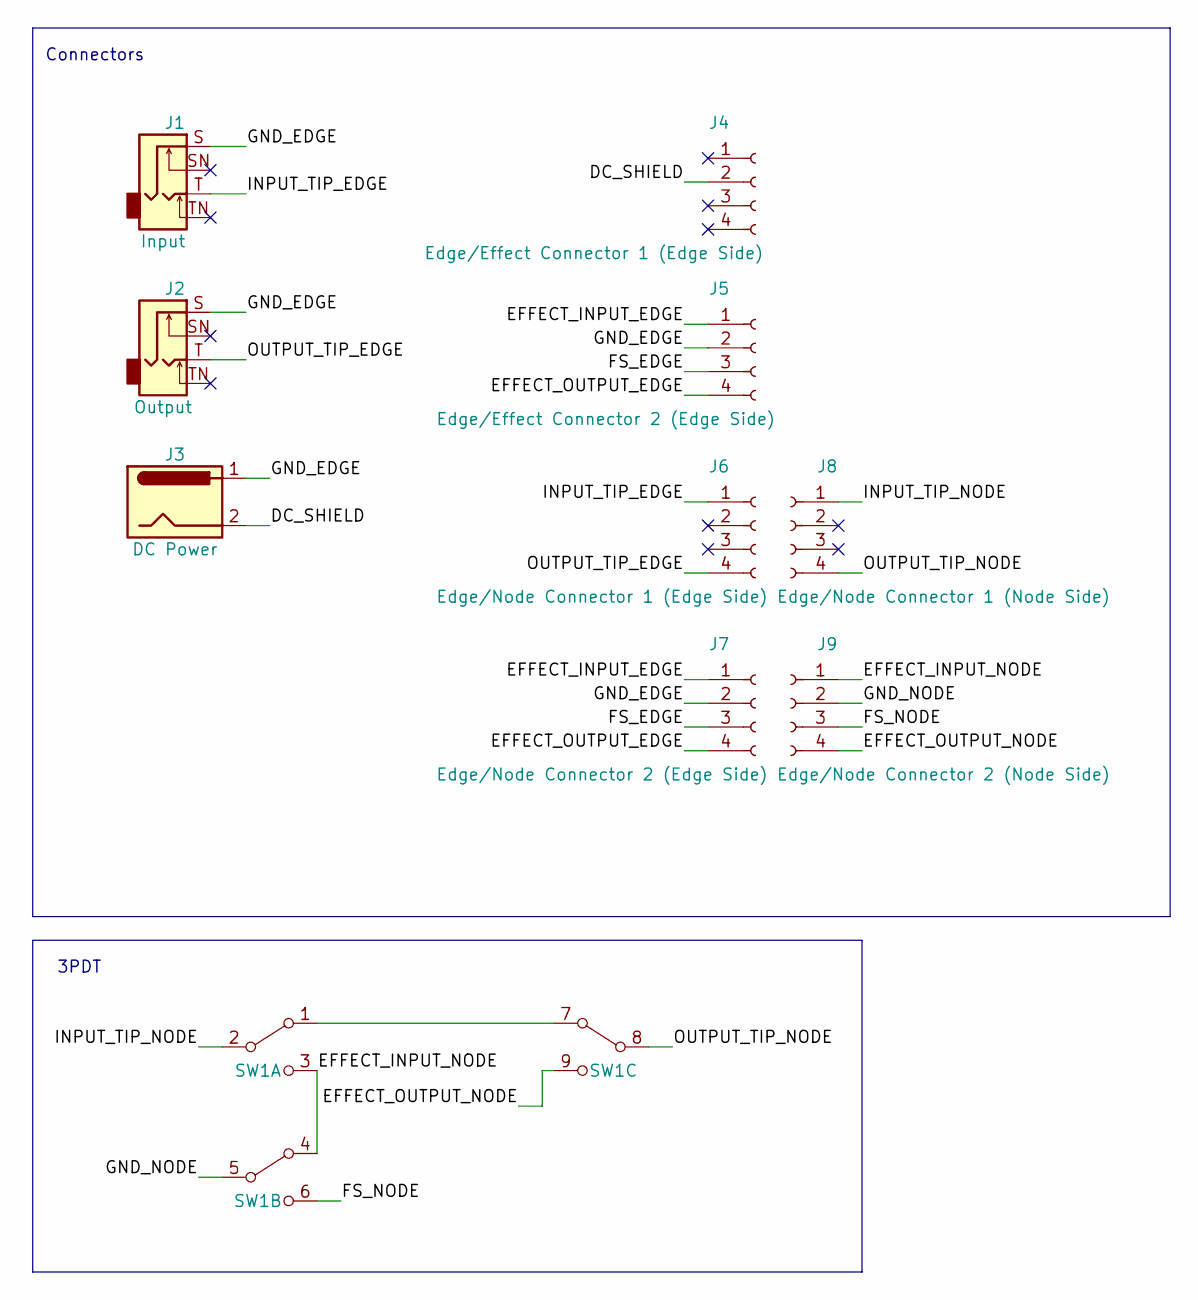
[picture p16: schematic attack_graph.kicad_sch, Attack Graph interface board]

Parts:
J1: Input; Jack_6.35mm_Neutrik_NMJ4HCD2_Horizontal
J2: Output; Jack_6.35mm_Neutrik_NMJ4HCD2_Horizontal
J3: DC Power; BarrelJack_GCT_DCJ200-10-A_Horizontal
J4: Edge/Effect Connector 1 (Edge Side); Molex_PicoBlade_53047-0410_1x04_P1.25mm_Vertical
J5: Edge/Effect Connector 2 (Edge Side); Molex_PicoBlade_53047-0410_1x04_P1.25mm_Vertical
J6: Edge/Node Connector 1 (Edge Side); Molex_PicoBlade_53047-0410_1x04_P1.25mm_Vertical
J7: Edge/Node Connector 2 (Edge Side); Molex_PicoBlade_53047-0410_1x04_P1.25mm_Vertical
J8: Edge/Node Connector 1 (Node Side); Molex_PicoBlade_53047-0410_1x04_P1.25mm_Vertical
J9: Edge/Node Connector 2 (Node Side); Molex_PicoBlade_53047-0410_1x04_P1.25mm_Vertical
SW1: Footswitch; SW_3PDT_SOLDER_LUGS

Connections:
/DC_SHIELD: J3.2, J4.2
/EFFECT_INPUT_EDGE: J5.1, J7.1
/EFFECT_INPUT_NODE: J9.1, SW1.3 (A3), SW1.4 (B1)
/EFFECT_OUTPUT_EDGE: J5.4, J7.4
/EFFECT_OUTPUT_NODE: J9.4, SW1.9 (C3)
/FS_EDGE: J5.3, J7.3
/FS_NODE: J9.3, SW1.6 (B3)
/GND_EDGE: J1.S, J2.S, J3.1, J5.2, J7.2
/GND_NODE: J9.2, SW1.5 (B2)
/INPUT_TIP_EDGE: J1.T, J6.1
/INPUT_TIP_NODE: J8.1, SW1.2 (A2)
/OUTPUT_TIP_EDGE: J2.T, J6.4
/OUTPUT_TIP_NODE: J8.4, SW1.8 (C2)
unnamed: SW1.1 (A1), SW1.7 (C1)

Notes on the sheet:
Connectors
3PDT

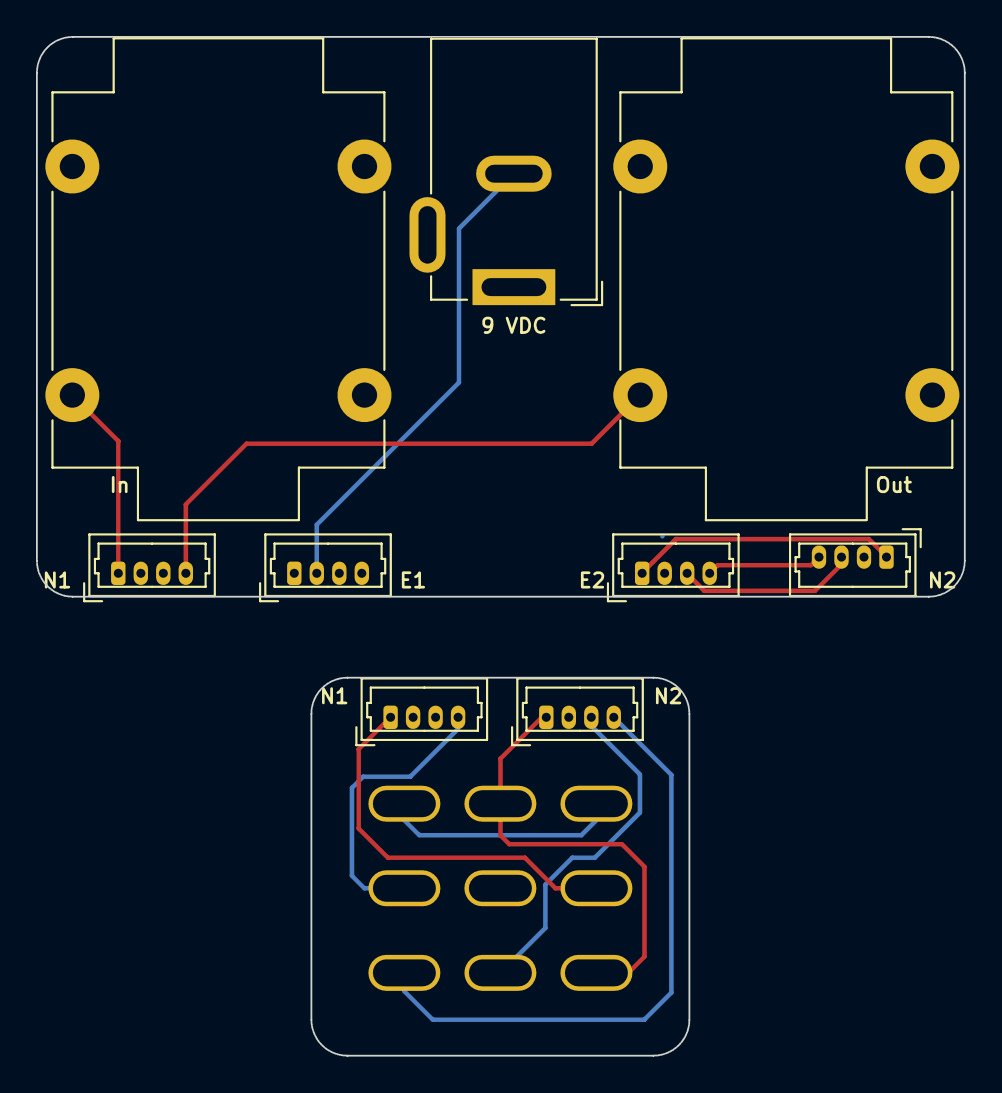
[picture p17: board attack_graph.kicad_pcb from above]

Board: 2 copper layers, 51.5 x 56.6 mm, 10 parts (1 on the bottom side), 14 nets.

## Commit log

2023-03-02 initial checkin for attack graph utility pcb design v0.01
    [attack_graph.kicad_pcb, attack_graph.kicad_sch]
2023-03-02 change name to Noise Floor
    [noise_floor.kicad_pcb, noise_floor.kicad_sch]
2023-03-03 fix ordering of IO/Switch board connectors
    [noise_floor.kicad_pcb, noise_floor.kicad_sch]
2023-03-03 Offload DC protection and LED indicator to "noise floor" utility boards
    - much rerouting and layout work, but functionally the same
    [noise_floor.kicad_pcb, noise_floor.kicad_sch]
2023-03-03 fix minor layout issue
    [noise_floor.kicad_pcb]
2023-03-03 rename schematic file with version number
2023-03-03 bump version number on schematic, oops
    [noise_floor.kicad_sch]
2023-03-03 v0.03 updates:
    - switch to SMD resistor and diode to save space (particularly on footswitch board)
    - move IO and DC jacks to bottom of board and ensure they're on the correct side
    - consolidate to a single effect board connector.
    [noise_floor.kicad_pcb, noise_floor.kicad_sch]
2023-03-04 update gitignore, random inconsequential changes to accomodate splitting boards
    [noise_floor.kicad_pcb]
2023-03-04 Some updates based on feedback from freestompboxes.org folks:
    - Add back thermal reliefs on ground pads
    - Switch to stereo jacks for improved mechanical support
    - Use switched symbol/footprint for DC Barrel jack, correct circuit to suit (still need to add switching on input jack)
    - Add 3D models for various parts (courtesy of Vasily Kashirin - https://grabcad.com/vasily.kashirin-1/models?page=1)
    [noise_floor.kicad_pcb, noise_floor.kicad_sch]
2023-03-04 fix a couple DRCs and bump rev
    [noise_floor.kicad_pcb, noise_floor.kicad_sch]
2023-03-05 v0.05, added switched power input and optional battery connection
    [noise_floor.kicad_pcb, noise_floor.kicad_sch]
2023-03-05 Remove ground from output switch line, fix ground split ground plane
    [noise_floor.kicad_pcb, noise_floor.kicad_sch]
2023-03-05 slight adjustment to input switch behavior, add note about chassis ground
    [noise_floor.kicad_pcb, noise_floor.kicad_sch]
2023-03-05 add script to generate schematic, saving time at release. also embed an SVG schematic in README.
2023-03-05 add script to split into io and switch board, then export gerbers
2023-03-08 add amphenol phone jack footprint
2023-03-10 update schematic plotting script to create the directory if it doesn't exist
2023-03-10 Fix errata from v0.03 prototype inspection:
    - Switch to narrower amphenol phone jacks to better fit within 125B enclosure
    - Swap pin ordering for picoblade connections on IO board, as retail cable assemblies swap pin order
    -
    Also:
    - Add JST XH header for battery connection
    Another commit will complete the reroute shortly.
    [noise_floor.kicad_pcb, noise_floor.kicad_sch]
2023-03-10 finish routing for v0.1 revision
    [noise_floor.kicad_pcb]
2023-03-11 rearrange layout of schematic
    [noise_floor.kicad_sch]
2023-03-11 and plot updated schematic
2023-03-13 Update to latest stable kicad version:
    - fixed issue rendering certain 3d models in color
    - had to fix some text rendering changes
    [noise_floor.kicad_pcb]
2023-03-16 Address issues identified in hardware rev v0.1
    - ACJS-MHOM footprint was pinned backwards. Confirmed operation when flipped to other side of board + rotated backwards.
    - Fix silkscreen: Move DC jack label within board bounds, add battery +/- indicators
    - Slightly shift DC power jack to better align to enclosure bounds.
    [noise_floor.kicad_pcb, noise_floor.kicad_sch]
2023-03-16 update renders and schematic for v0.2
2023-03-24 Fix one issue discovered in testing of v0.2 hardware
    - swap nets on battery JST connector
    [noise_floor.kicad_pcb, noise_floor.kicad_sch]
2023-03-26 improve power filtering and move to more SMD components
    [noise_floor.kicad_pcb, noise_floor.kicad_sch]
2023-03-27 v0.30 includes a new "ux" board, with the initial feature set:
    - board-to-board connector interface for expandability
    - three potentiometers and three SPDT switches
    [noise_floor-ux.kicad_pcb, noise_floor.kicad_pcb, noise_floor.kicad_sch]
2023-03-27 Add pot adjustment resistors, adapt to different layout and reroute, bump to v0.31
    [noise_floor-ux.kicad_pcb, noise_floor.kicad_pcb, noise_floor.kicad_sch]
2023-03-27 Further iteration on UX board:
    - Change to square body pots and bump count to six
    - Change to 25-pin board-to-board connectors (and improve footprint)
    - Change optional pot adjustment to 1206 smt resistors
    - Update layout/routing to suit
    [noise_floor.kicad_pcb, noise_floor.kicad_sch]
2023-03-27 minor tweaks to schematic layout
    [noise_floor.kicad_pcb, noise_floor.kicad_sch]
